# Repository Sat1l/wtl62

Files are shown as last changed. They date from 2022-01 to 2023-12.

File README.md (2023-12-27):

# wtl62

#### Hardware disclaimer
The folder structure is fucked up and probably wont be fixed as i see no reason for this.
Top case part (plate) is located in the bottom case part folder, and this one is located in the general pcb folder. Yeah.
There's also Willing To Live Better 62 inside, but this one proly wont' see a light of day as there prolly aint no interest in this design. Have fun.

#### firmware use guide
clone wtl62 folder to qmk_firmware/keyboards
#### Compiling
`qmk compile -kb WTL62 -km keymap`
- replace keymap with keymap you would like to compile. This repo contains only default keymap
#### Flashing default .hex file
[QMK Toolbox](https://github.com/qmk/qmk_toolbox) is the easiest way to do this. Short pins `gnd` and `rst` on yours MCU to reset
#### Using Vial
1. Flash `wtl62_via.hex` file to the keyboard
2. Open Vial
3. Go to File>Sideload VIA JSON...
4. Select `via.json` file
5. Voila! Now you can configure wtl62 using Vial

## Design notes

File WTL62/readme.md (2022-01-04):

# WTL62

WTL62

*A short description of the keyboard/project*

* Keyboard Maintainer: [Satell1te](https://github.com/yourusername)
* Hardware Supported: *The PCBs, controllers supported*
* Hardware Availability: *Links to where you can find this hardware*

Make example for this keyboard (after setting up your build environment):

    make WTL62:default

Flashing example for this keyboard:

    make WTL62:default:flash

See the [build environment setup](https://docs.qmk.fm/#/getting_started_build_tools) and the [make instructions](https://docs.qmk.fm/#/getting_started_make_guide) for more information. Brand new to QMK? Start with our [Complete Newbs Guide](https://docs.qmk.fm/#/newbs).

## Bootloader

Enter the bootloader in 3 ways:

* **Bootmagic reset**: Hold down the key at (0,0) in the matrix (usually the top left key or Escape) and plug in the keyboard
* **Physical reset button**: Briefly press the button on the back of the PCB - some may have pads you must short instead
* **Keycode in layout**: Press the key mapped to `RESET` if it is available

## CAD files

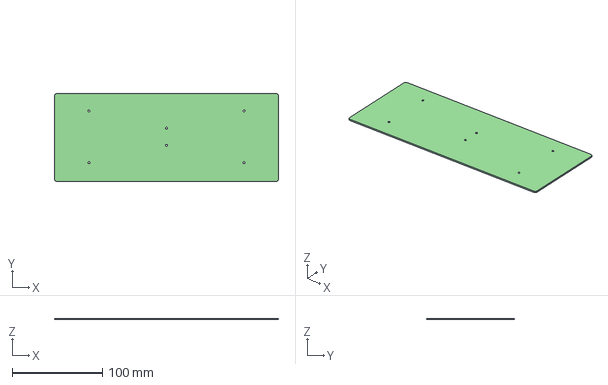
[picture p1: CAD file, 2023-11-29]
WTL-62 - KiCad/WTL-62-BOTTOM/WTL-62-BOTTOM.step
247.7 x 96.8 x 1.60 mm

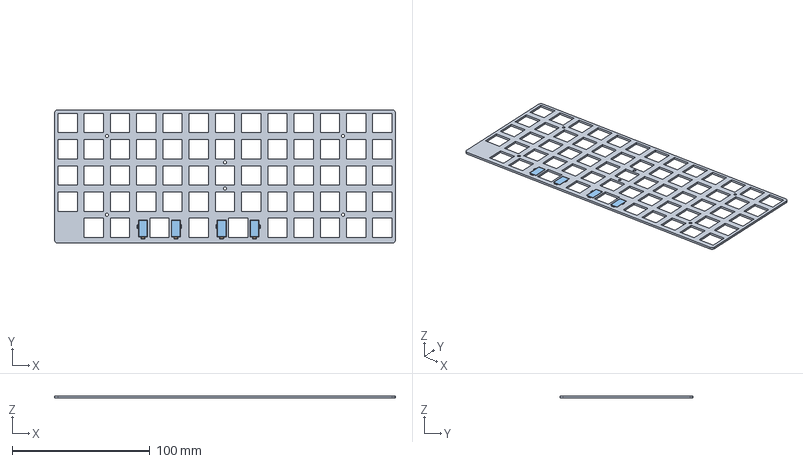
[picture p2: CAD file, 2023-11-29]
WTL-62 - KiCad/WTL-62-BOTTOM/WTL-62-TOP/WTL-62-TOP.step
247.7 x 96.8 x 1.60 mm

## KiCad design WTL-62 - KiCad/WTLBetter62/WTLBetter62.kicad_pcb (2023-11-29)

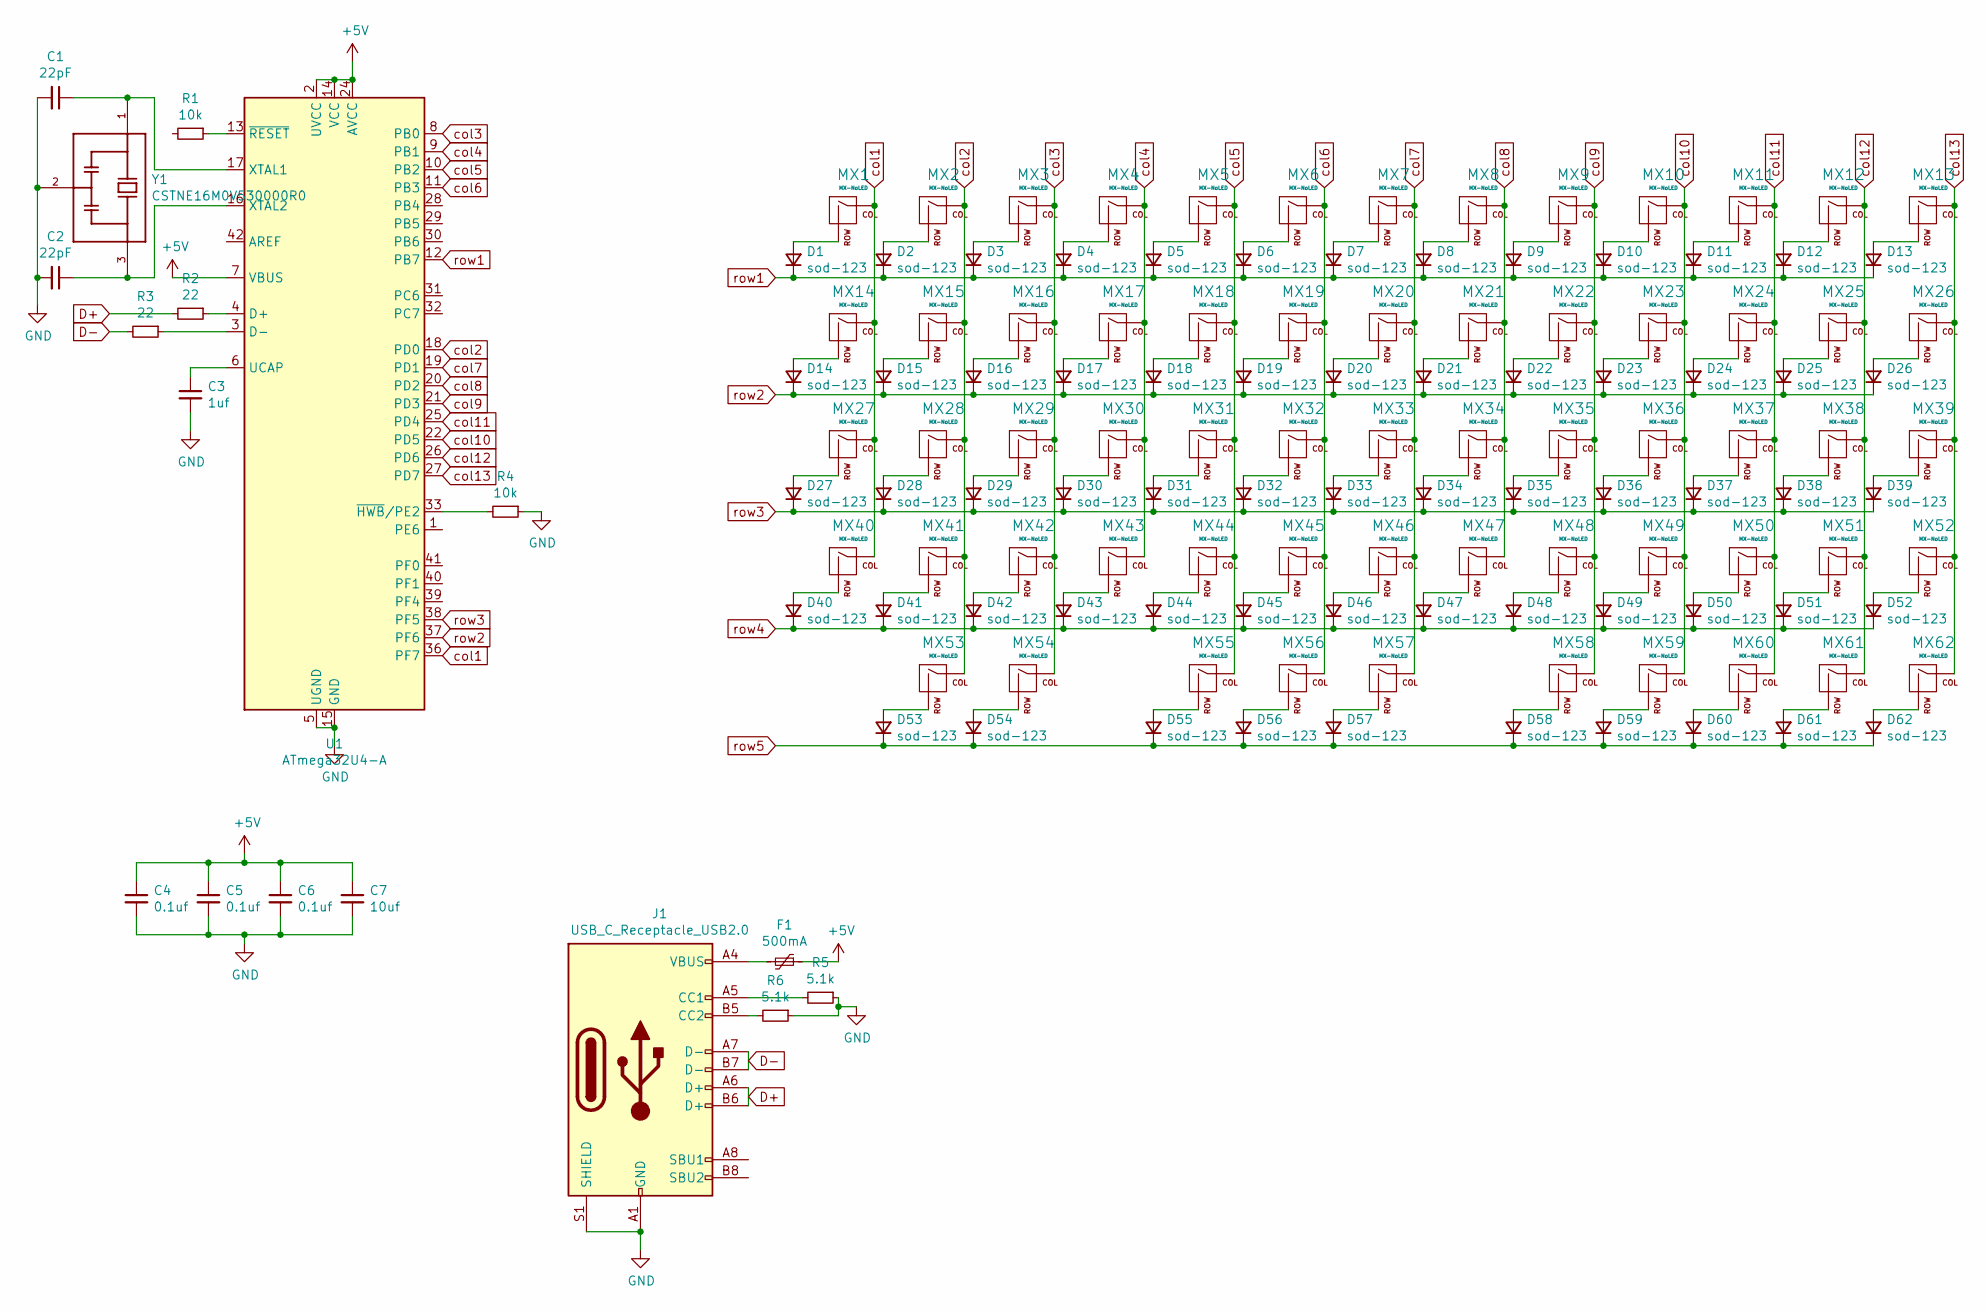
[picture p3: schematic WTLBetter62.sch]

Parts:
C1, C2: 22pF; C_0805_2012Metric
C3: 1uf; C_0805_2012Metric
C4, C5, C6: 0.1uf; C_0805_2012Metric
C7: 10uf; C_0805_2012Metric
D1, D2, D3, D4, D5, D6, D7, D8, D9, D10, D11, D12, D13, D14, D15, D16, D17, D18, D19, D20, D21, D22, D23, D24, D25, D26, D27, D28, D29, D30, D31, D32, D33, D34, D35, D36, D37, D38, D39, D40, D41, D42, D43, D44, D45, D46, D47, D48, D49, D50, D51, D52, D53, D54, D55, D56, D57, D58, D59, D60, D61, D62: sod-123; D3_SMD_v2
F1: 500mA; Fuse_1206_3216Metric
J1: USB_C_Receptacle_USB2.0; easyeda_C168688
MX1, MX2, MX3, MX4, MX5, MX6, MX7, MX8, MX9, MX10, MX11, MX12, MX13, MX14, MX15, MX16, MX17, MX18, MX19, MX20, MX21, MX22, MX23, MX24, MX25, MX26, MX27, MX28, MX29, MX30, MX31, MX32, MX33, MX34, MX35, MX36, MX37, MX38, MX39, MX40, MX41, MX42, MX43, MX44, MX45, MX46, MX47, MX48, MX49, MX50, MX51, MX52, MX53, MX54, MX55, MX56, MX57, MX58, MX59, MX60, MX61, MX62: MX-NoLED; CherryMX_Hotswap
R1, R4: 10k; R_0805_2012Metric
R2, R3: 22; R_0805_2012Metric
R5, R6: 5.1k; R_0805_2012Metric
U1: ATmega32U4-A; TQFP-44_10x10mm_P0.8mm
Y1: CSTNE16M0V530000R0; OSC_CSTNE16M0V530000R0; PARTREV JGC42-8853B

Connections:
+5V: C4.1, C5.1, C6.1, C7.1, F1.1, U1.2 (UVCC), U1.7 (VBUS), U1.14 (VCC), U1.24 (AVCC), U1.34 (VCC), U1.44 (AVCC)
D+: J1.A6 (D+), J1.B6 (D+), R2.2
D-: J1.A7 (D-), J1.B7 (D-), R3.2
GND: C1.2, C2.2, C3.2, C4.2, C5.2, C6.2, C7.2, J1.A1 (GND), J1.A12 (GND), J1.B1 (GND), J1.B12 (GND), J1.S1 (SHIELD), R4.1, R5.1, R6.1, U1.5 (UGND), U1.15 (GND), U1.23 (GND), U1.35 (GND), U1.43 (GND), Y1.2
unnamed: C1.1, U1.17 (XTAL1), Y1.1
unnamed: C2.1, U1.16 (XTAL2), Y1.3
unnamed: C3.1, U1.6 (UCAP)
unnamed: D1.2 (A), MX1.2 (ROW)
unnamed: D2.2 (A), MX2.2 (ROW)
unnamed: D3.2 (A), MX3.2 (ROW)
unnamed: D4.2 (A), MX4.2 (ROW)
unnamed: D5.2 (A), MX5.2 (ROW)
unnamed: D6.2 (A), MX6.2 (ROW)
unnamed: D7.2 (A), MX7.2 (ROW)
unnamed: D8.2 (A), MX8.2 (ROW)
unnamed: D9.2 (A), MX9.2 (ROW)
unnamed: D10.2 (A), MX10.2 (ROW)
unnamed: D11.2 (A), MX11.2 (ROW)
unnamed: D12.2 (A), MX12.2 (ROW)
unnamed: D13.2 (A), MX13.2 (ROW)
unnamed: D14.2 (A), MX14.2 (ROW)
unnamed: D15.2 (A), MX15.2 (ROW)
unnamed: D16.2 (A), MX16.2 (ROW)
unnamed: D17.2 (A), MX17.2 (ROW)
unnamed: D18.2 (A), MX18.2 (ROW)
unnamed: D19.2 (A), MX19.2 (ROW)
unnamed: D20.2 (A), MX20.2 (ROW)
unnamed: D21.2 (A), MX21.2 (ROW)
unnamed: D22.2 (A), MX22.2 (ROW)
unnamed: D23.2 (A), MX23.2 (ROW)
unnamed: D24.2 (A), MX24.2 (ROW)
unnamed: D25.2 (A), MX25.2 (ROW)
unnamed: D26.2 (A), MX26.2 (ROW)
unnamed: D27.2 (A), MX27.2 (ROW)
unnamed: D28.2 (A), MX28.2 (ROW)
unnamed: D29.2 (A), MX29.2 (ROW)
unnamed: D30.2 (A), MX30.2 (ROW)
unnamed: D31.2 (A), MX31.2 (ROW)
unnamed: D32.2 (A), MX32.2 (ROW)
unnamed: D33.2 (A), MX33.2 (ROW)
unnamed: D34.2 (A), MX34.2 (ROW)
unnamed: D35.2 (A), MX35.2 (ROW)
unnamed: D36.2 (A), MX36.2 (ROW)
unnamed: D37.2 (A), MX37.2 (ROW)
unnamed: D38.2 (A), MX38.2 (ROW)
unnamed: D39.2 (A), MX39.2 (ROW)
unnamed: D40.2 (A), MX40.2 (ROW)
unnamed: D41.2 (A), MX41.2 (ROW)
unnamed: D42.2 (A), MX42.2 (ROW)
unnamed: D43.2 (A), MX43.2 (ROW)
unnamed: D44.2 (A), MX44.2 (ROW)
unnamed: D45.2 (A), MX45.2 (ROW)
unnamed: D46.2 (A), MX46.2 (ROW)
unnamed: D47.2 (A), MX47.2 (ROW)
unnamed: D48.2 (A), MX48.2 (ROW)
unnamed: D49.2 (A), MX49.2 (ROW)
unnamed: D50.2 (A), MX50.2 (ROW)
unnamed: D51.2 (A), MX51.2 (ROW)
unnamed: D52.2 (A), MX52.2 (ROW)
unnamed: D53.2 (A), MX53.2 (ROW)
unnamed: D54.2 (A), MX54.2 (ROW)
unnamed: D55.2 (A), MX55.2 (ROW)
unnamed: D56.2 (A), MX56.2 (ROW)
unnamed: D57.2 (A), MX57.2 (ROW)
unnamed: D58.2 (A), MX58.2 (ROW)
unnamed: D59.2 (A), MX59.2 (ROW)
unnamed: D60.2 (A), MX60.2 (ROW)
unnamed: D61.2 (A), MX61.2 (ROW)
unnamed: D62.2 (A), MX62.2 (ROW)
unnamed: F1.2, J1.A4 (VBUS), J1.A9 (VBUS), J1.B4 (VBUS), J1.B9 (VBUS)
unnamed: J1.A5 (CC1), R5.2
unnamed: J1.B5 (CC2), R6.2
unnamed: R1.1, U1.13 (~RESET)
unnamed: R2.1, U1.4 (D+)
unnamed: R3.1, U1.3 (D-)
unnamed: R4.2, U1.33 (~HWB~/PE2)
col1: MX1.1 (COL), MX14.1 (COL), MX27.1 (COL), MX40.1 (COL), U1.36 (PF7)
col2: MX2.1 (COL), MX15.1 (COL), MX28.1 (COL), MX41.1 (COL), MX53.1 (COL), U1.18 (PD0)
col3: MX3.1 (COL), MX16.1 (COL), MX29.1 (COL), MX42.1 (COL), MX54.1 (COL), U1.8 (PB0)
col4: MX4.1 (COL), MX17.1 (COL), MX30.1 (COL), MX43.1 (COL), U1.9 (PB1)
col5: MX5.1 (COL), MX18.1 (COL), MX31.1 (COL), MX44.1 (COL), MX55.1 (COL), U1.10 (PB2)
col6: MX6.1 (COL), MX19.1 (COL), MX32.1 (COL), MX45.1 (COL), MX56.1 (COL), U1.11 (PB3)
col7: MX7.1 (COL), MX20.1 (COL), MX33.1 (COL), MX46.1 (COL), MX57.1 (COL), U1.19 (PD1)
col8: MX8.1 (COL), MX21.1 (COL), MX34.1 (COL), MX47.1 (COL), U1.20 (PD2)
col9: MX9.1 (COL), MX22.1 (COL), MX35.1 (COL), MX48.1 (COL), MX58.1 (COL), U1.21 (PD3)
col10: MX10.1 (COL), MX23.1 (COL), MX36.1 (COL), MX49.1 (COL), MX59.1 (COL), U1.22 (PD5)
col11: MX11.1 (COL), MX24.1 (COL), MX37.1 (COL), MX50.1 (COL), MX60.1 (COL), U1.25 (PD4)
col12: MX12.1 (COL), MX25.1 (COL), MX38.1 (COL), MX51.1 (COL), MX61.1 (COL), U1.26 (PD6)
col13: MX13.1 (COL), MX26.1 (COL), MX39.1 (COL), MX52.1 (COL), MX62.1 (COL), U1.27 (PD7)
row1: D1.1 (K), D2.1 (K), D3.1 (K), D4.1 (K), D5.1 (K), D6.1 (K), D7.1 (K), D8.1 (K), D9.1 (K), D10.1 (K), D11.1 (K), D12.1 (K), D13.1 (K), U1.12 (PB7)
row2: D14.1 (K), D15.1 (K), D16.1 (K), D17.1 (K), D18.1 (K), D19.1 (K), D20.1 (K), D21.1 (K), D22.1 (K), D23.1 (K), D24.1 (K), D25.1 (K), D26.1 (K), U1.37 (PF6)
row3: D27.1 (K), D28.1 (K), D29.1 (K), D30.1 (K), D31.1 (K), D32.1 (K), D33.1 (K), D34.1 (K), D35.1 (K), D36.1 (K), D37.1 (K), D38.1 (K), D39.1 (K), U1.38 (PF5)
row4: D40.1 (K), D41.1 (K), D42.1 (K), D43.1 (K), D44.1 (K), D45.1 (K), D46.1 (K), D47.1 (K), D48.1 (K), D49.1 (K), D50.1 (K), D51.1 (K), D52.1 (K)
row5: D53.1 (K), D54.1 (K), D55.1 (K), D56.1 (K), D57.1 (K), D58.1 (K), D59.1 (K), D60.1 (K), D61.1 (K), D62.1 (K)

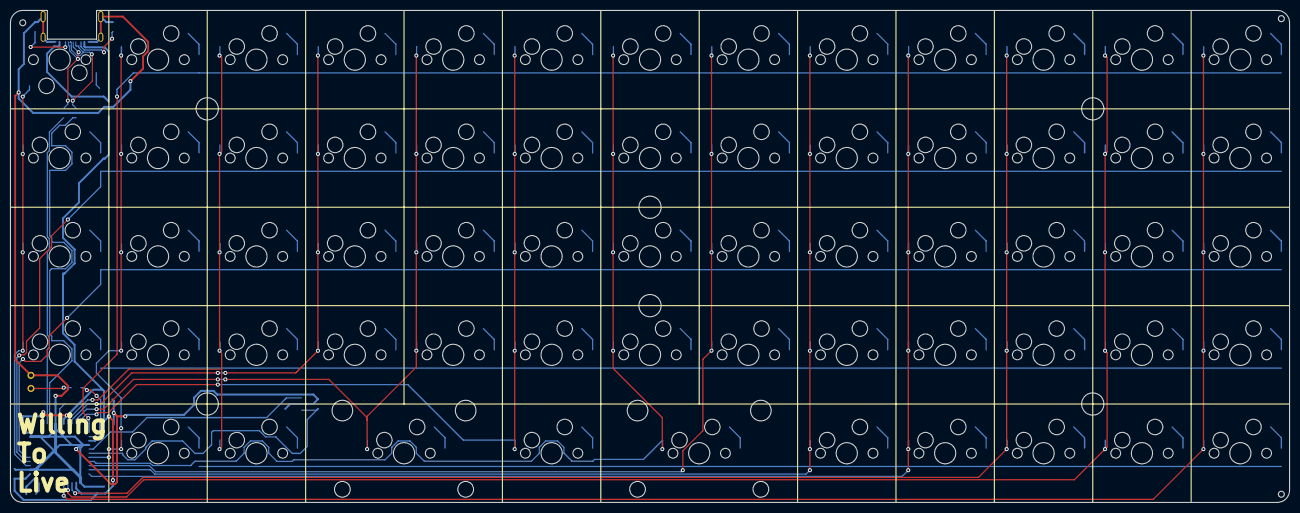
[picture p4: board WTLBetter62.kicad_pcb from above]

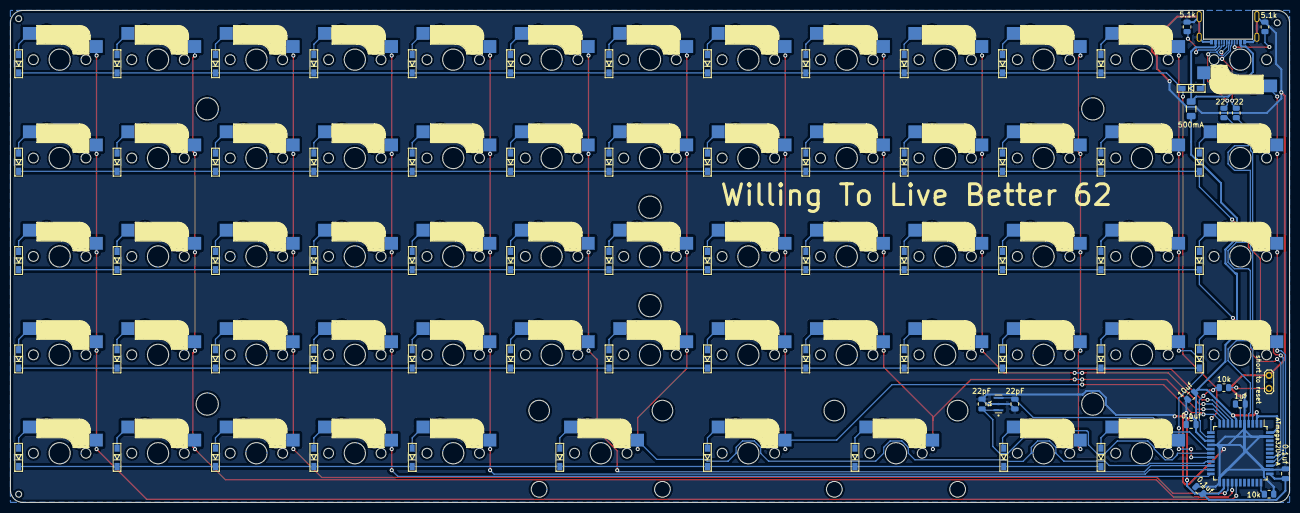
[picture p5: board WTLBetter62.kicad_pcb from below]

Board: 2 copper layers, 247.7 x 95.3 mm, 147 parts (79 on the bottom side), 94 nets.

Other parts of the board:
Ref**: Val**; M2_HOLE_v2
Ref**#2, Ref**#3, Ref**#4, Ref**#5, Ref**#6: Val**; M2_HOLE_v2

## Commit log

2022-01-04 ¯\_(ツ)_/¯
2023-07-04 Open sourced the KiCad design
2023-11-29 NOW FOR REAL ADDED KICAD FILES
2023-11-29 Revert "NOW FOR REAL ADDED KICAD FILES"
    This reverts commit faa8c233870fdadf60d61d6ff53c29565a21c0cd.
2023-11-29 NOW 4REAL ADDED THE PCB FILES
    [WTL-62-BOTTOM-B_Cu.gbl, WTL-62-BOTTOM-B_Mask.gbs, WTL-62-BOTTOM-B_SilkS.gbo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]
